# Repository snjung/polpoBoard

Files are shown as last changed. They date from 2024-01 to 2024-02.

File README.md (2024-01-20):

# polpoBoard

## Introduction
This repository compiles code and documentation for an electronic scoreboard. It has been successfully operated for several years and was continuously updated and improved.
The idea and inspiration comes from the awesome folks from Westbury on Severn Cricket Club
You can find their blog with tons of useful information on the project at https://buildyourownscoreboard.wordpress.com/

The main idea is to have a Raspberry Pi acting as a web-server and providing control of the scoreboard via a simple webpage to connected devices. The Raspberry Pi will transmit the data to be shown on the scoreboard to an arduino board via serial interface. The Arduino will then control the hardware. Currently this includes
- Custom Build 7-segment elements to show goals and time left of the current game
- A 12V car horn used for signaling end of game / half-time
- Display-Panels build of 8x8 dot-matrix LED elements to show the names of the teams

### Hardware

#### 7-Segment Elements

The 7-Segment elements are custom build and consist of 12V-LED stripes or bars. 

### Control Scheme

To control the high number of LED elements by a single microcontroller (4 x 2digits x 7 LED elements), the schematics uses shift registers for multiplexing.
Some great explanation of the functionality for a shift register can be found at https://www.mikrocontroller.net/articles/AVR-Tutorial:_Schieberegister
Each shift register provides 8 output channels and can be used to control one individual digit of the scoreboard. All shift registers can be cascaded (serial_out connected to serial_in of the next IC) and controlled via one single data pin.
The electrical signals we need are:
- **Serial Data**: Sequence of bit-values indicating if a specific output channel should be enabled/disabled. Due to the shifting, the first bit send to the shift registers will end up to be the last channel of the last register in the chain.
- **Clock signal**, that is in sync with the data signal. On each positive flank, the current value on the serial-data line will be stored in the 1st bit of an internal register of the IC (shift register) and already stored values will be shifted to the next address. Data, that was stored at the last position in the shift register will be send to serial_out / the next shift register IC). Depending on the specific IC, the PIN is usually called SCK or SRCK.
- **Release signal**. When all data has been transmitted thus the internal shift registers of the ICs have been properly set, a rising flank of this signal will cause the current values of the shift register to be transfered to the output register. Only then will the outputs of the ICs actually change state. The corresponding Pin is usually called RCK.
There are some additional signals, that are not essential but could be used for further control of the ICs:
- **Output activation signal** (Usually diaignated G). Can be used to enable/disable the outputs indipendent of the state of the output register. For the relevant ICs, 0V indicates outputs enabled. Therefore, if this function is not required, the corresponding pin can be wired to GND
- **Clear signal**: Can be used to erase all data from the shift register (Setting all bits to 0). If this function is not required, the corresponding pin can be wired to +5V. Default designator for the pin is SCL

For controling the shift registers, we can use the SPI-bus of the Arduino, since it already comes with a resource-efficient implementation for sending serial data with a synchronous clock signal. 
SPI is a three wire communication bus that is intended to connect a number of slave devices to one master device in parallel. The electrical signals are:
- SLK (or SCK / SCLK): Clock signal for synchronising Master and Slave - In our case this corresponds to SCK/SRCK of the shift registers
- MOSI (Master output Slave input) (also called PICO): Used to send data from the Master to the slave - In our case this corresponds to the Serial Data send to the input of the first shift register
- MISO (Master input Slave Output) (also called POCI): Used to send data back to the master - In our case not required

Since all slave devices are connected to the SPI bus in parallel, there must be a mechanism to identify the device that is selected for communication. For this purpose, the SPI-bus uses an additional signal / wire for each slave device, that enables communcication. This pin usually is designated as SS (slave select). The default state of the SS-lines is +5V. During communication with one individual slave, its SS-line will be pulled to GND (for the duration of the communication).

The Shift registers have no slave select pin. However, it is still possible to use these devices in parallel with outher SPI devices by using the RCK pin (Release signal). Although the ICs will process all data (also data meant for other SPI-devices on the bus) and change the internal shift registers accordingly, there won't be any unintended change to the storage register and output channels without setting the RCK-signal. Since the Transfer from shift- to output registers is triggered by a positive flank on the RCK-line, the SS-select signal can be used and directly being hooked to the RCK pin. One should be aware, that when using multiple devices on the SPI-bus, the state of the shift registers might have some arbitrary state after some time. Before enabling the release signal, one must always (re-)set the shift-registers to its correct/intended state.

### Hardware

A convenient choice is the TPIC6B595N. The advantage is, that its open-drain DMOS transistors are intended for high current operation and can directly drive the LED-elements.  With 8 outputs, one TPIC6B595N can provide current to all elements of one 7-segment display. The TPIC6B595N has a continuous sink-current capability of 150mA on each output channel.

If the LED-stripes to be used would sink more than 150mA () the TPIC6B595N would have to be reduced. I could not find suitable devices, that combine the shifter funtionality with the high current output capability. It would probably be advisable to use a dedicated (low current) shifter like a 74HC595 in combination with a multi-channel transistor IC like the ULN2803A. The ULN2803A is capable of sinking 500mA continuously.   

### Software

#### Arduino Softwa

#### Serial Communication

Raspberry Pi and Arduino have to exchange information on the scoreboard status via serial port. The Arduino Firmware uses  CmdMessenger by Thijs Elenbaas to implement the serial communication. Project repository can be found at https://github.com/thijse/Arduino-CmdMessenger. CmdMessengers message format:

``Cmd Id, param 1, [...] , param N;``

Default field seperator is a comma, default command sepeartor is semi-colon.
For our application, the seperators are changed to:
- field seperator: ,
- command seperator: #

There is a Python client to communicate with an Arduino implementing this protocol: https://github.com/harmsm/PyCmdMessenger

#### Control of 7-segment elements

For controlling the 7-segment displays via the TPIC6B595N, the communication and control of the shift register has to be done via SPI. The specific control scheme to control the drain-outputs of the shift registers is implemented in a simple library called polposhifter. This library uses the standard SPI-library that is pre-installed with arduino IDE.

#### Raspberry Pi

For setting-up the Raspberry Pi one can closely followed along the instructions from https://buildyourownscoreboard.wordpress.com/setting-up-the-raspberry-jessie/
The instructions are based on Raspeerry OS 8 (Jessie) and php versiion 5. I used more up-to-date software versions, which works with minimal modification to the. The main steps are:
- Download and install the Raspberry imager from  https://www.raspberrypi.com/software/
- Use this tool to prepare the micro-SD card for the Raspberry (I use a Rev 3 B+ ) with Raspberry Pi OS in lite version (without desktop environement). The Version proposed and used by the installer was bullseye (version 11)
- All further steps can be followed from the linked instructions, with some minor adjustements:
  - When doing the configuration modifications (sudo raspi-config), the mentioned options to be changed are not part of advanced options but instad can be found unter inderface options. When deactivation the serial console I1 lets you activate SSH remote command line access. I6 lets you disable shell and kernel messages on the serial connection. It also asks you, if serial port hardware should be deactivated (choose no) 
  - Installing more recent php-version is straight forward. Just use sudo apt-get install php (instead of php5) and libapache2-mod-phpxxx with the specific php-version that apt-get got tfromit's repositories.
  
  The main operation principle is as follows:
  - The Raspberry hosts an apache webserver, delivering an interactive webpage to connected clients (PC, tablet or smartphone). This has the required interface elements to control the scorepoard and GUI elements to show its current status.
  - The Apache Server runs with enhanced rights (AllowOverride set to All, apache user www-data has user rights to dialout / access serial interface)
  - The web-interface uses javascript routines to implement the scoreboards logic. In essence, all logic is implemented on this level, the arduino is just getting information via serial port on the content, that should be shown on the physical scoreboard. The logic specific javascript-code is part of scoreboard.js.

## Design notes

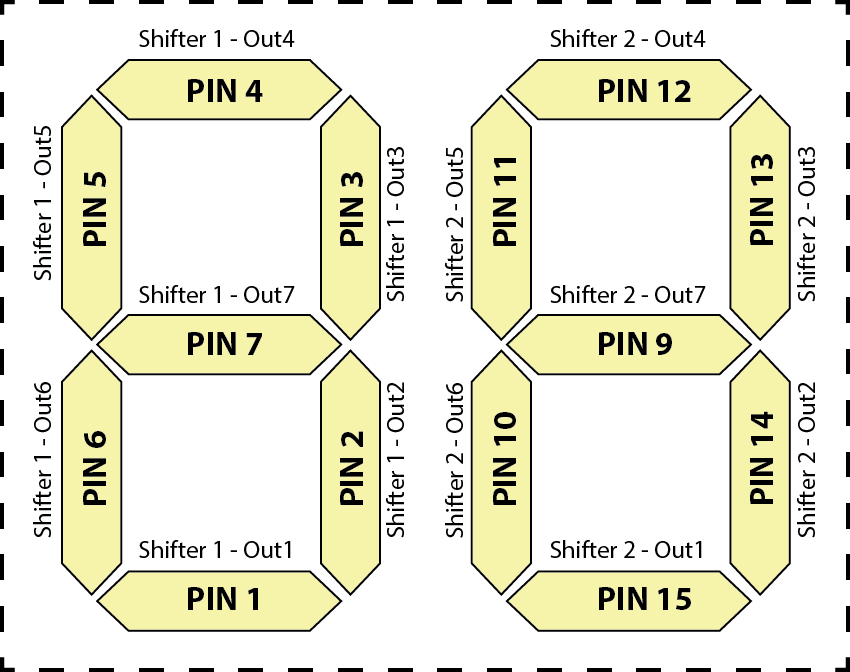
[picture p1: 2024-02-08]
Ressources/7-Segments/Pin-Belegung.png

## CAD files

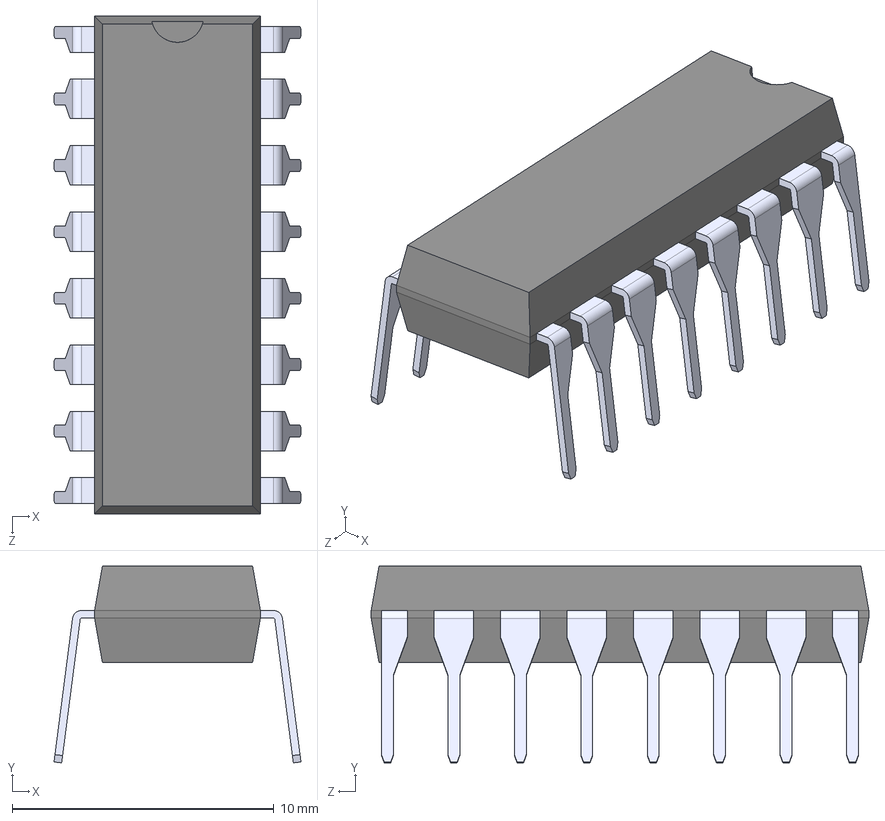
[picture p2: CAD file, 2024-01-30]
KiCAD/Polpoboard_PCB/3D-Models/LOGIC-74HC595N_DIP16_.step
9.44 x 7.53 x 19.0 mm

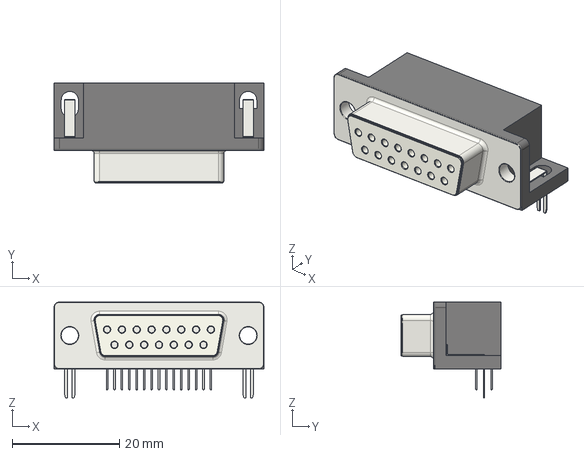
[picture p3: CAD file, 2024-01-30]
KiCAD/Polpoboard_PCB/3D-Models/DSUB-15_Female_Horizontal_P2.77x2.84mm_EdgePinOffset7.70mm_Housed_MountingHolesOffset9.12mm.step
39.2 x 18.7 x 17.9 mm

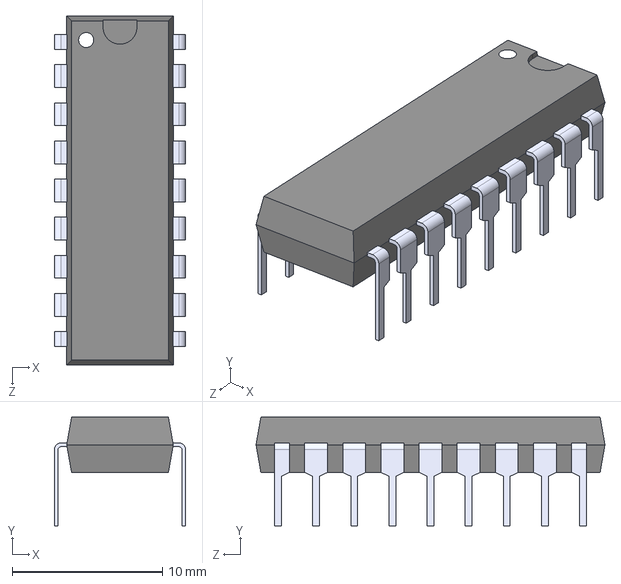
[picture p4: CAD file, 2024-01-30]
KiCAD/Polpoboard_PCB/3D-Models/ULN2803A.step
8.75 x 7.23 x 23.2 mm

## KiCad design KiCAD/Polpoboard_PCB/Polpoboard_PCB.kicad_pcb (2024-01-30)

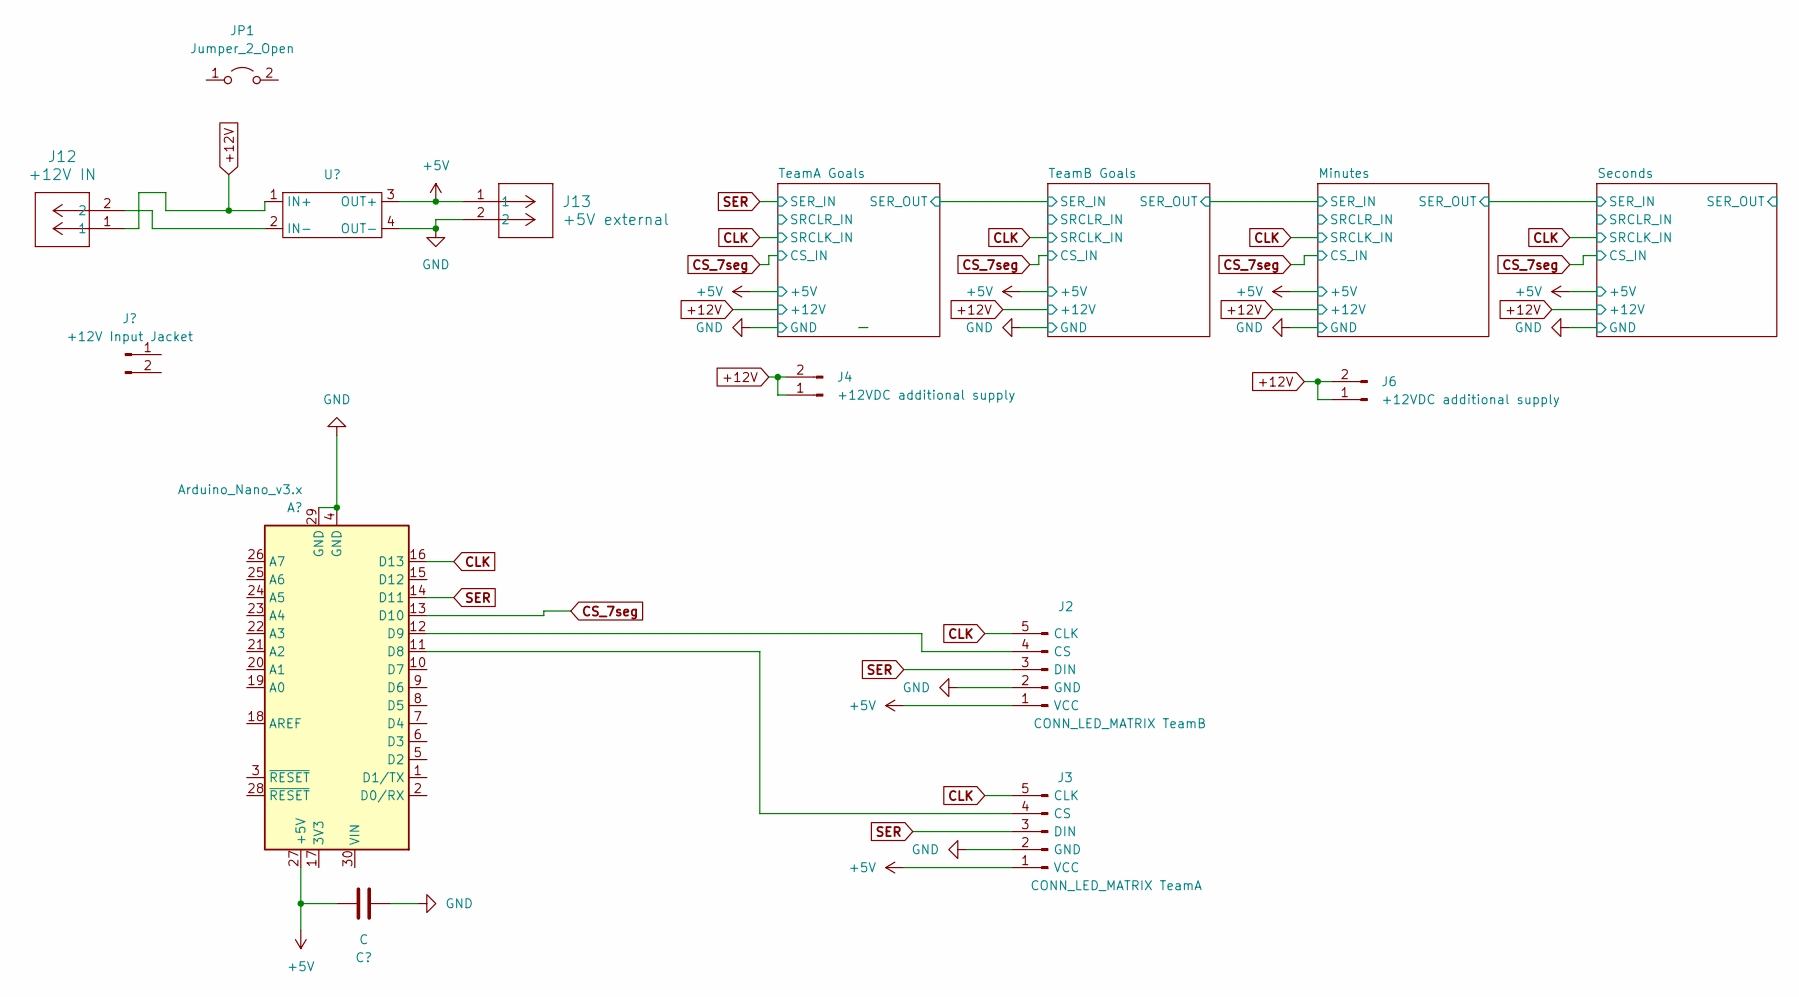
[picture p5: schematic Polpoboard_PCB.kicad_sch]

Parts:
A1: Arduino_Nano_v3.x; Arduino_Nano
C1: C; CP_Radial_D6.3mm_P2.50mm
J1: +12V Input Jacket
J2: CONN_LED_MATRIX TeamB; JST_XH_B5B-XH-AM_1x05_P2.50mm_Vertical
J3: CONN_LED_MATRIX TeamA; JST_XH_B5B-XH-AM_1x05_P2.50mm_Vertical
J4, J6: +12VDC additional supply; TerminalBlock_Altech_AK300-2_P5.00mm
J12: +12V IN; CONN2_710002_WRE
J13: +5V external; CONN2_710002_WRE
JP1: Jumper_2_Open
U1: XL4005_DC-DC

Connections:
+5V: A1.27 (+5V), C1.2, J2.1 (VCC), J3.1 (VCC), J13.1, U1.3 (OUT+); also elsewhere on the board
+12V: J4.1, J4.2, J6.1, J6.2, J12.1, U1.1 (IN+); also elsewhere on the board
CLK: A1.16 (D13), J2.5 (CLK), J3.5 (CLK); also elsewhere on the board
CS_7seg: A1.13 (D10); also elsewhere on the board
GND: A1.4 (GND), A1.29 (GND), C1.1, J2.2 (GND), J3.2 (GND), J13.2, U1.4 (OUT-); also elsewhere on the board
unnamed: A1.11 (D8), J3.4 (CS)
unnamed: A1.12 (D9), J2.4 (CS)
unnamed: J12.2, U1.2 (IN-)
SER: A1.14 (D11), J2.3 (DIN), J3.3 (DIN); also elsewhere on the board

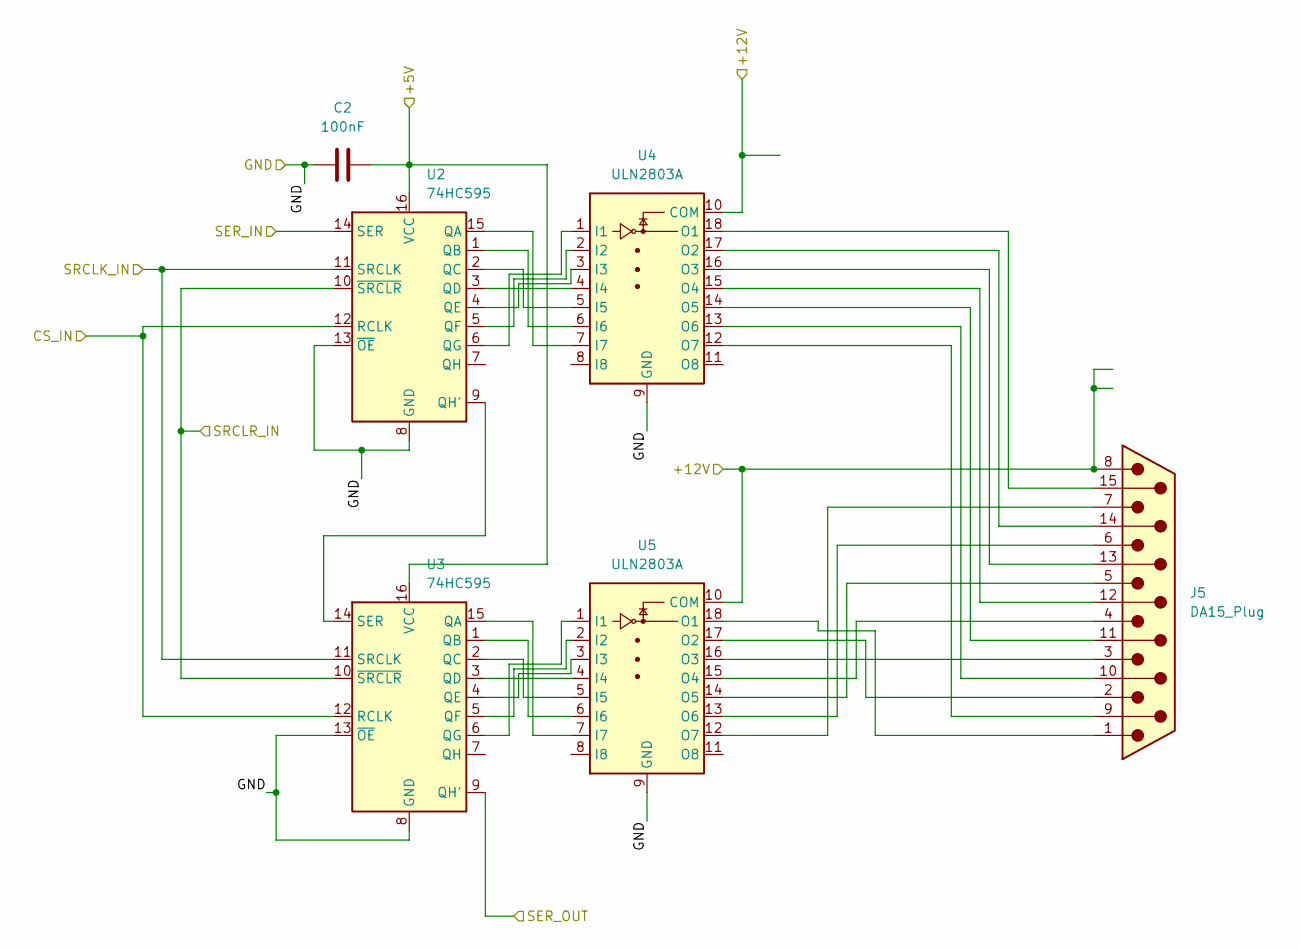
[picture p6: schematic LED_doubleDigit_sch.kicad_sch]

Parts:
C2: 100nF; C_Disc_D4.7mm_W2.5mm_P5.00mm
J5: DA15_Plug; DSUB-15
U2, U3: 74HC595; 74HC595N
U4, U5: ULN2803A

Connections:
+5V: C2.2, U2.16 (VCC), U3.16 (VCC); also elsewhere on the board
+12V: J5.8, U4.10 (COM), U5.10 (COM); also elsewhere on the board
/TeamA Goals/SER_OUT: U3.9 (QH'); also elsewhere on the board
/TeamA Goals/SRCLR_IN: U2.10 (~SRCLR), U3.10 (~SRCLR)
CLK: U2.11 (SRCLK), U3.11 (SRCLK); also elsewhere on the board
CS_7seg: U2.12 (RCLK), U3.12 (RCLK); also elsewhere on the board
GND: C2.1, U2.8 (GND), U2.13 (~OE), U3.8 (GND), U3.13 (~OE), U4.9 (GND), U5.9 (GND); also elsewhere on the board
unnamed: J5.9, U4.12 (O7)
unnamed: J5.10, U4.13 (O6)
unnamed: J5.12, U4.15 (O4)
unnamed: J5.13, U4.16 (O3)
unnamed: J5.14, U4.17 (O2)
unnamed: J5.15, U4.18 (O1)
unnamed: J5.11 (P111), U4.14 (O5)
unnamed: U2.15 (QA), U4.7 (I7)
unnamed: U2.1 (QB), U4.6 (I6)
unnamed: U2.2 (QC), U4.5 (I5)
unnamed: U2.3 (QD), U4.4 (I4)
unnamed: U2.4 (QE), U4.3 (I3)
unnamed: U2.5 (QF), U4.2 (I2)
unnamed: U2.6 (QG), U4.1 (I1)
unnamed: U2.9 (QH'), U3.14 (SER)
unnamed: U3.15 (QA), U5.7 (I7)
unnamed: U3.1 (QB), U5.6 (I6)
unnamed: U3.2 (QC), U5.5 (I5)
unnamed: U3.3 (QD), U5.4 (I4)
unnamed: U3.4 (QE), U5.3 (I3)
unnamed: U3.5 (QF), U5.2 (I2)
unnamed: U3.6 (QG), U5.1 (I1)
unnamed: J5.1, U5.18 (O1)
unnamed: J5.2, U5.17 (O2)
unnamed: J5.3, U5.16 (O3)
unnamed: J5.4, U5.15 (O4)
unnamed: J5.5, U5.14 (O5)
unnamed: J5.6, U5.13 (O6)
unnamed: J5.7, U5.12 (O7)
SER: U2.14 (SER); also elsewhere on the board

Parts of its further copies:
C3, C4, C5: 100nF; C_Disc_D4.7mm_W2.5mm_P5.00mm
J7, J9, J11: DA15_Plug; DSUB-15
U6, U7, U10, U11, U14, U15: 74HC595; 74HC595N
U8, U9, U12, U13, U16, U17: ULN2803A

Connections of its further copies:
+5V: C3.2, C4.2, C5.2, U6.16 (VCC), U7.16 (VCC), U10.16 (VCC), U11.16 (VCC), U14.16 (VCC), U15.16 (VCC); also elsewhere on the board
+12V: J7.8, J9.8, J11.8, U8.10 (COM), U9.10 (COM), U12.10 (COM), U13.10 (COM), U16.10 (COM), U17.10 (COM); also elsewhere on the board
/Minutes/SER_IN: U7.9 (QH'), U10.14 (SER)
/Minutes/SER_OUT: U11.9 (QH'), U14.14 (SER)
/Minutes/SRCLR_IN: U10.10 (~SRCLR), U11.10 (~SRCLR)
/Seconds/SER_OUT: U15.9 (QH')
/Seconds/SRCLR_IN: U14.10 (~SRCLR), U15.10 (~SRCLR)
/TeamA Goals/SER_OUT: U6.14 (SER); also elsewhere on the board
/TeamB Goals/SRCLR_IN: U6.10 (~SRCLR), U7.10 (~SRCLR)
CLK: U6.11 (SRCLK), U7.11 (SRCLK), U10.11 (SRCLK), U11.11 (SRCLK), U14.11 (SRCLK), U15.11 (SRCLK); also elsewhere on the board
CS_7seg: U6.12 (RCLK), U7.12 (RCLK), U10.12 (RCLK), U11.12 (RCLK), U14.12 (RCLK), U15.12 (RCLK); also elsewhere on the board
GND: C3.1, C4.1, C5.1, U6.8 (GND), U6.13 (~OE), U7.8 (GND), U7.13 (~OE), U8.9 (GND), U9.9 (GND), U10.8 (GND), U10.13 (~OE), U11.8 (GND), U11.13 (~OE), U12.9 (GND), U13.9 (GND), U14.8 (GND), U14.13 (~OE), U15.8 (GND), U15.13 (~OE), U16.9 (GND), U17.9 (GND); also elsewhere on the board
unnamed: J7.9, U8.12 (O7)
unnamed: J7.10, U8.13 (O6)
unnamed: J7.12, U8.15 (O4)
unnamed: J7.13, U8.16 (O3)
unnamed: J7.14, U8.17 (O2)
unnamed: J7.15, U8.18 (O1)
unnamed: J7.11 (P111), U8.14 (O5)
unnamed: J9.9, U12.12 (O7)
unnamed: J9.10, U12.13 (O6)
unnamed: J9.12, U12.15 (O4)
unnamed: J9.13, U12.16 (O3)
unnamed: J9.14, U12.17 (O2)
unnamed: J9.15, U12.18 (O1)
unnamed: J9.11 (P111), U12.14 (O5)
unnamed: J11.9, U16.12 (O7)
unnamed: J11.10, U16.13 (O6)
unnamed: J11.12, U16.15 (O4)
unnamed: J11.13, U16.16 (O3)
unnamed: J11.14, U16.17 (O2)
unnamed: J11.15, U16.18 (O1)
unnamed: J11.11 (P111), U16.14 (O5)
unnamed: U6.15 (QA), U8.7 (I7)
unnamed: U6.1 (QB), U8.6 (I6)
unnamed: U6.2 (QC), U8.5 (I5)
unnamed: U6.3 (QD), U8.4 (I4)
unnamed: U6.4 (QE), U8.3 (I3)
unnamed: U6.5 (QF), U8.2 (I2)
unnamed: U6.6 (QG), U8.1 (I1)
unnamed: U6.9 (QH'), U7.14 (SER)
unnamed: U7.15 (QA), U9.7 (I7)
unnamed: U7.1 (QB), U9.6 (I6)
unnamed: U7.2 (QC), U9.5 (I5)
unnamed: U7.3 (QD), U9.4 (I4)
unnamed: U7.4 (QE), U9.3 (I3)
unnamed: U7.5 (QF), U9.2 (I2)
unnamed: U7.6 (QG), U9.1 (I1)
unnamed: J7.1, U9.18 (O1)
unnamed: J7.2, U9.17 (O2)
unnamed: J7.3, U9.16 (O3)
unnamed: J7.4, U9.15 (O4)
unnamed: J7.5, U9.14 (O5)
unnamed: J7.6, U9.13 (O6)
unnamed: J7.7, U9.12 (O7)
unnamed: U10.15 (QA), U12.7 (I7)
unnamed: U10.1 (QB), U12.6 (I6)
unnamed: U10.2 (QC), U12.5 (I5)
unnamed: U10.3 (QD), U12.4 (I4)
unnamed: U10.4 (QE), U12.3 (I3)
unnamed: U10.5 (QF), U12.2 (I2)
unnamed: U10.6 (QG), U12.1 (I1)
unnamed: U10.9 (QH'), U11.14 (SER)
unnamed: U11.15 (QA), U13.7 (I7)
unnamed: U11.1 (QB), U13.6 (I6)
unnamed: U11.2 (QC), U13.5 (I5)
unnamed: U11.3 (QD), U13.4 (I4)
unnamed: U11.4 (QE), U13.3 (I3)
unnamed: U11.5 (QF), U13.2 (I2)
unnamed: U11.6 (QG), U13.1 (I1)
unnamed: J9.1, U13.18 (O1)
unnamed: J9.2, U13.17 (O2)
unnamed: J9.3, U13.16 (O3)
unnamed: J9.4, U13.15 (O4)
unnamed: J9.5, U13.14 (O5)
unnamed: J9.6, U13.13 (O6)
unnamed: J9.7, U13.12 (O7)
unnamed: U14.15 (QA), U16.7 (I7)
unnamed: U14.1 (QB), U16.6 (I6)
unnamed: U14.2 (QC), U16.5 (I5)
unnamed: U14.3 (QD), U16.4 (I4)
unnamed: U14.4 (QE), U16.3 (I3)
unnamed: U14.5 (QF), U16.2 (I2)
unnamed: U14.6 (QG), U16.1 (I1)
unnamed: U14.9 (QH'), U15.14 (SER)
unnamed: U15.15 (QA), U17.7 (I7)
unnamed: U15.1 (QB), U17.6 (I6)
unnamed: U15.2 (QC), U17.5 (I5)
unnamed: U15.3 (QD), U17.4 (I4)
unnamed: U15.4 (QE), U17.3 (I3)
unnamed: U15.5 (QF), U17.2 (I2)
unnamed: U15.6 (QG), U17.1 (I1)
unnamed: J11.1, U17.18 (O1)
unnamed: J11.2, U17.17 (O2)
unnamed: J11.3, U17.16 (O3)
unnamed: J11.4, U17.15 (O4)
unnamed: J11.5, U17.14 (O5)
unnamed: J11.6, U17.13 (O6)
unnamed: J11.7, U17.12 (O7)

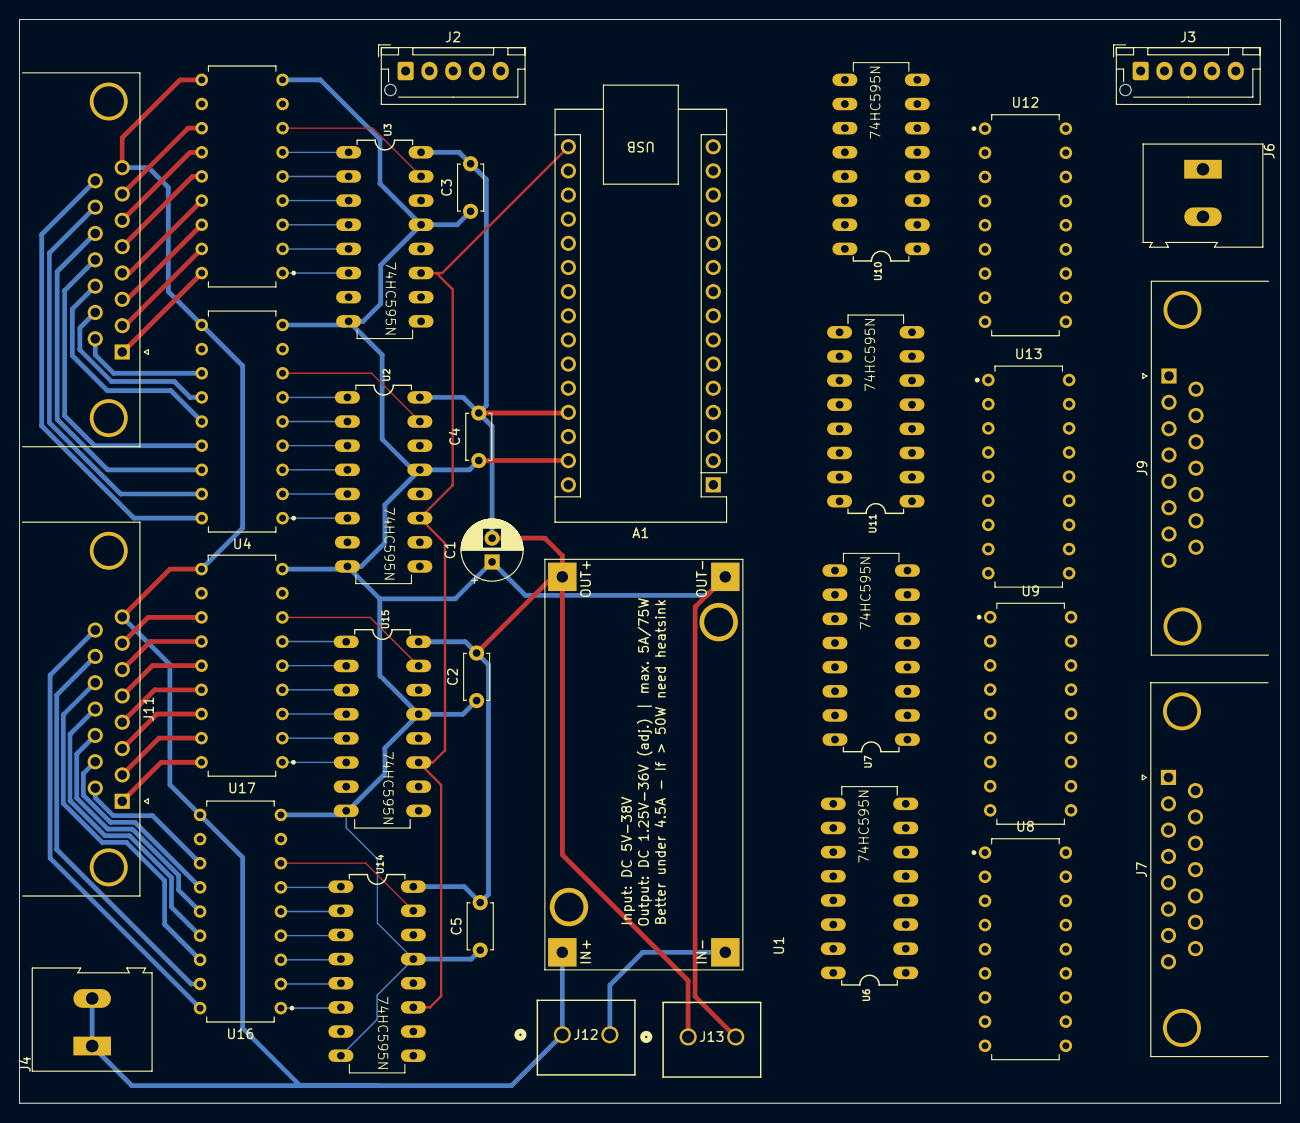
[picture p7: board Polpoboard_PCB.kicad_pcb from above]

Board: 2 copper layers, 132.6 x 114.0 mm, 33 parts (0 on the bottom side), 132 nets.

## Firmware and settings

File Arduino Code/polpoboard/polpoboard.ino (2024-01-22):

// Commands, the Raspberry will send to the Arduino
// Command to Update the Scoreboard (CMD-code 004):     4,TeamAScore,TeamBScore,TimeMinutes,TimeSeconds#

// Shifter library available from http://www.proto-pic.com/Resources/shifter.zip
#include <polpoShifter.h>

#include <polpoDisplay.h>

// CmdMessenger library available from https://github.com/dreamcat4/cmdmessenger
#include <CmdMessenger.h>

// Base64 library available from https://github.com/adamvr/arduino-base64
#include <Base64.h>

// Streaming4 library available from http://arduiniana.org/libraries/streaming/
#include <Streaming.h>

// set up the field seperators and command seperators.  
char field_separator = ',';
char command_separator = '#';

// set up the chharacter arrays we will use later
char teamAScore[2] = { '\0' };
char teamBScore[2] = { '\0' };
char minutes[2] = { '\0' };
char seconds[2] = { '\0' };
char quarter[2] = { '\0' };

// set up the headings 
char teamAHeading[] = "TeamA";
char teamBHeading[] = "TeamB";
char minutesHeading[] = "Minuten:";
char secondsHeading[] = "Sekunden:";
char quarterHeading[] = "Halbzeit:";

// Attach a new CmdMessenger object to the default Serial port
CmdMessenger cmdMessenger = CmdMessenger(Serial, field_separator, command_separator);

// dreamcat4 default
// ------------------ C M D  L I S T I N G ( T X / R X ) ---------------------

// We can define up to a default of 50 cmds total, including both directions (send + recieve)
// and including also the first 4 default command codes for the generic error handling.
// If you run out of message slots, then just increase the value of MAXCALLBACKS in CmdMessenger.h

// Commands we send from the Arduino to be received on the PC
enum
{
  kCOMM_ERROR    = 000, // Lets Arduino report serial port comm error back to the PC (only works for some comm errors)
  kACK           = 001, // Arduino acknowledges cmd was received
  kARDUINO_READY = 002, // After opening the comm port, send this cmd 02 from PC to check arduino is ready
  kERR           = 003, // Arduino reports badly formatted cmd, or cmd not recognised

  // Now we can define many more 'send' commands, coming from the arduino -> the PC, eg
  // kICE_CREAM_READY,
  // kICE_CREAM_PRICE,
  // For the above commands, we just call cmdMessenger.sendCmd() anywhere we want in our Arduino program.

  kSEND_CMDS_END, // Must not delete this line
};

// set up the shifter object
int confirmationPin = 6;
Shifter polpoShifter(8, confirmationPin);  // 8 digits (4x2), confirmation PIN to be discussed

void update_scoreboard()
{
  while ( cmdMessenger.available() )
  {
    
    // lets assume we always get the correctly formatted string
    // its lazy, but should be ok
    
    char buf[2] = { '\0' };             // Initiate a 4 byte buffer to hold the data
    char tempString[8] = { '\0' }; 
    
    // Team A Score
    cmdMessenger.copyString(buf, 2);
    strcpy(teamAScore,buf);
    cmdMessenger.sendCmd(kACK, teamAHeading);
    cmdMessenger.sendCmd(kACK, teamAScore);
    
    // Team B Score
    memset(buf, '\0', 2);               // Erase the buffer content
    cmdMessenger.copyString(buf, 2);
    strcpy(teamBScore,buf);
    cmdMessenger.sendCmd(kACK, teamBHeading);
    cmdMessenger.sendCmd(kACK, teamBScore);
    
    // Minutes
    memset(buf, '\0', 2);
    cmdMessenger.copyString(buf, 2);
    strcpy(minutes, buf);
    cmdMessenger.sendCmd(kACK, minutesHeading);
    cmdMessenger.sendCmd(kACK, minutes);
    
    // Seconds
    memset(buf, '\0', 2);
    cmdMessenger.copyString(buf, 2);
    strcpy(seconds, buf);
    cmdMessenger.sendCmd(kACK, secondsHeading);
    cmdMessenger.sendCmd(kACK, seconds);

    // Quarter
    memset(buf, '\0', 1);
    cmdMessenger.copyString(buf, 1);
    strcpy(quarter, buf);
    cmdMessenger.sendCmd(kACK, quarterHeading);
    cmdMessenger.sendCmd(kACK, quarter);


    strcpy(tempString,teamAScore);
    strcat(tempString,teamBScore);
    strcat(tempString,minutes);
    strcat(tempString,seconds);

    cmdMessenger.sendCmd(kACK, tempString);
    
    polpoShifter.display(tempString);
    
    
  }
}

void test_mode()
{
    char buf[] = { "Test Mode" };
    cmdMessenger.sendCmd(kACK, buf);
    polpoShifter.display("11122233");
}

// default dreamcat4 stuff

// ------------------ D E F A U L T  C A L L B A C K S -----------------------

void arduino_ready()
{
  // In response to ping. We just send a throw-away Acknowledgement to say "im alive"
  cmdMessenger.sendCmd(kACK,"Arduino ready");
}

void unknownCmd()
{
  // Default response for unknown commands and corrupt messages
  cmdMessenger.sendCmd(kERR,"Unknown command");
}

// ------------------ E N D  C A L L B A C K  M E T H O D S ------------------

// Commands we send from the PC and want to recieve on the Arduino.
// We must define a callback function in our Arduino program for each entry in the list below vv.
// They start at the address kSEND_CMDS_END defined ^^ above as 004
messengerCallbackFunction messengerCallbacks[] = 
{
  update_scoreboard,            // 004
  test_mode,                    // 005
  NULL
};
// Its also possible (above ^^) to implement some symetric commands, when both the Arduino and
// PC / host are using each other's same command numbers. However we recommend only to do this if you
// really have the exact same messages going in both directions. Then specify the integers (with '=')


// ------------------ S E T U P ----------------------------------------------

void attach_callbacks(messengerCallbackFunction* callbacks)
{
  int i = 0;
  int offset = kSEND_CMDS_END;
  while(callbacks[i])
  {
    cmdMessenger.attach(offset+i, callbacks[i]);
    i++;
  }
}

void setup()
{
  // Listen on serial connection for messages from the pc
  Serial.begin(57600); // Arduino Uno, Mega, with AT8u2 USB

  // cmdMessenger.discard_LF_CR(); // Useful if your terminal appends CR/LF, and you wish to remove them
  cmdMessenger.print_LF_CR();   // Make output more readable whilst debugging in Arduino Serial Monitor
  
  // Attach default / generic callback methods
  cmdMessenger.attach(kARDUINO_READY, arduino_ready);
  cmdMessenger.attach(unknownCmd);

  // Attach my application's user-defined callback methods
  attach_callbacks(messengerCallbacks);

  arduino_ready();
  
  // Set the displays to 000 on boot
  //shifterSet1.display("000000000");
  //shifterSet2.display("000000");
  polpoShifter.display("--0--0--0");
}

// ------------------ M A I N ( ) --------------------------------------------

// Timeout handling
long timeoutInterval = 2000; // 2 seconds
long previousMillis = 0;
int counter = 0;

void timeout()
{
  // blink
  if (counter % 2)
    digitalWrite(13, HIGH);
  else
    digitalWrite(13, LOW);
  counter ++;
}  

void loop()
{
  
  // Process incoming serial data, if any
  cmdMessenger.feedinSerialData();

  // handle timeout function, if any
  if (  millis() - previousMillis > timeoutInterval )
  {
    timeout();
    previousMillis = millis();
  }
  
}

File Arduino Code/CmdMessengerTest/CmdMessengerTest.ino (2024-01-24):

#include <CmdMessenger.h>  // CmdMessenger

// Blinking led variables 
unsigned long previousToggleLed = 0;   // Last time the led was toggled
bool ledState                   = 0;   // Current state of Led
const int kBlinkLed             = 13;  // Pin of internal Led


// set up the field seperators and command seperators.  
char field_separator = ',';
char command_separator = '#';

char *nameTeamA = "Team A";
char *nameTeamB = "Team B";

char teamAScore[2] = "00";
char teamBScore[2] = "00";
char minutes[2] = "00";
char seconds[2] = "00";
char halftime[2] = "00";


// Attach a new CmdMessenger object to the default Serial port
CmdMessenger cmdMessenger = CmdMessenger(Serial, field_separator, command_separator);


// This is the list of recognized commands. These can be commands that can either be sent or received. 
// In order to receive, attach a callback function to these events
enum
{
  // Commands
  kAcknowledge         , // Command to acknowledge that cmd was received          COMMAND 0
  kError               , // Command to report errors                              COMMAND 1
  kSetTeamName         , // Command to set the Team Name for LED-Matrix           COMMAND 2 
  kUpdateScoreboard    , // Command to update goals, halftimem minute and seconds COMMAND 3
};

// Commands we send from the PC and want to receive on the Arduino.
// We must define a callback function in our Arduino program for each entry in the list below.

void attachCommandCallbacks()
{
  // Attach callback methods
  cmdMessenger.attach(OnUnknownCommand);
  cmdMessenger.attach(kSetTeamName, setTeamName);
  cmdMessenger.attach(kUpdateScoreboard, updateScoreboard);
}

// ------------------  C A L L B A C K S -----------------------

// Called when a received command has no attached function
void OnUnknownCommand()
{
  cmdMessenger.sendCmd(kError,"Command without attached callback");
}

// Callback function that responds that Arduino is ready (has booted up)
void OnArduinoReady()
{
  cmdMessenger.sendCmd(kAcknowledge,"Arduino ready");
}

void setTeamName()
{
  int team = cmdMessenger.readInt16Arg();
  if (team == 0) {
    char *nameTeamA = cmdMessenger.readStringArg();
    cmdMessenger.sendCmd(kAcknowledge,"Received Command to change Team A Name");
    cmdMessenger.sendCmd(kAcknowledge,nameTeamA);
  } else {
    char *nameTeamB = cmdMessenger.readStringArg();
    cmdMessenger.sendCmd(kAcknowledge,"Received Command to change Team B Name");
    cmdMessenger.sendCmd(kAcknowledge,nameTeamB);
  }
}


void updateScoreboard()
{
    //String buf;
    char *buf;
    uint8_t i;
    int halftime;
    char tempString[8] = { '\0' }; 
    buf = cmdMessenger.readStringArg(); //Read TeamA Score
    strncpy(tempString, buf, 2);
    buf = cmdMessenger.readStringArg(); //Read TeamB Score
    strncat(tempString, buf, 2);
    buf = cmdMessenger.readStringArg(); //Read Minutes
    strncat(tempString, buf, 2);
    buf = cmdMessenger.readStringArg(); //Read Seconds
    strncat(tempString, buf, 2);
    halftime = cmdMessenger.readInt16Arg(); //Read halftime
    cmdMessenger.sendCmd(kAcknowledge, "Scoreboard-String");
    cmdMessenger.sendCmd(kAcknowledge, tempString);
    cmdMessenger.sendCmd(kAcknowledge, "Halftime");
    cmdMessenger.sendCmd(kAcknowledge, halftime);

    //polpoShifter.display(tempString);
}

// ------------------ M A I N  ----------------------

// Setup function
void setup() 
{
  // Listen on serial connection for messages from the pc
  Serial.begin(115200); 

  // Adds newline to every command
  cmdMessenger.printLfCr();   

  // Attach my application's user-defined callback methods
  attachCommandCallbacks();

  // Send the status to the PC that says the Arduino has booted
  cmdMessenger.sendCmd(kAcknowledge,"Arduino has started!");

  // set pin for blink LED
  pinMode(kBlinkLed, OUTPUT);
}

// Returns if it has been more than interval (in ms) ago. Used for periodic actions
bool hasExpired(unsigned long &prevTime, unsigned long interval) {
  if (  millis() - prevTime > interval ) {
    prevTime = millis();
    return true;
  } else     
    return false;
}

// Loop function
void loop() 
{
  // Process incoming serial data, and perform callbacks
  cmdMessenger.feedinSerialData();

  // Toggle LED periodically. If the LED does not toggle every 2000 ms, 
  // this means that cmdMessenger are taking a longer time than this  
  if (hasExpired(previousToggleLed,2000)) // Toggle every 2 secs
  {
    toggleLed();  
  } 
}

// Toggle led state 
void toggleLed()
{  
  ledState = !ledState;
  digitalWrite(kBlinkLed, ledState?HIGH:LOW);
}  

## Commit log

2024-01-19 Update README.md
    Added information on shift registers and SPI-bus
2024-01-20 Collecting all the pieces from prior work
    [character-values.ods]
2024-01-22 LED-Matrix with Double Height Initial work on Arduino implementation
2024-01-22 Added batch file to copy arduino files to the default library folder
2024-01-24 Added Arduino test integration for CmdMessenger Latest version of library has changed cmd-set modification required
2024-01-24 Initial work on Arduino Controller PCB
    [LED_doubleDigit_sch.kicad_sch, Polpoboard_controller.kicad_pcb, Polpoboard_controller.kicad_sch]
2024-01-25 restrucutred Arduino folder
2024-01-30 Updated version of KiCAD PCB files
    [DSUB-15_Female_Horizontal_P2.77x2.84mm_EdgePinOffset7.70mm_Housed_MountingHolesOffset9.12mm.step, LED_doubleDigit_sch.kicad_sch, LOGIC-74HC595N_DIP16_.step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]
2024-02-08 Minor updates to the PCB
    [LED_doubleDigit_sch.kicad_sch, Polpoboard_PCB.kicad_sch]

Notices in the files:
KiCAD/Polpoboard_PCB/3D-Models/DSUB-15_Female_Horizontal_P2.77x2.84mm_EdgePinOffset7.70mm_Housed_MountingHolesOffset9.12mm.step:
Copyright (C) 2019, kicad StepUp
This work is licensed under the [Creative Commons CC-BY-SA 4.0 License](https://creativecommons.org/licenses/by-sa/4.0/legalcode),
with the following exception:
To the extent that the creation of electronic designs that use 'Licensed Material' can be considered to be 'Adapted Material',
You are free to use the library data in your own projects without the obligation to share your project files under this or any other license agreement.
